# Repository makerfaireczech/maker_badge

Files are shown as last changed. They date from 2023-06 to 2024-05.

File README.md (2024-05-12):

# Maker badge
The Maker badge board is the official badge board for Maker Faire's in the Czech republic. The main purpose is to show visitors/exhibitors name and/or project, but the secondary goal is to have at each Maker Faire some interactive game so people can have more fun at the time of the visit.

This board supports [Arduino](https://github.com/espressif/arduino-esp32) and [CircuitPython](https://learn.adafruit.com/welcome-to-circuitpython) platform. 

CircuitPython will be **primary** platform for this board because it is very easy to use, and anybody who will buy a board at some Maker Fair should be able very easily change (at least) her/his name on the display, so anybody knows the name of the person when they start chatting about something.  

I will try to add as many examples for both platforms, as I could, but I already saw few very interesting projects.

## How to use this board in 5 steps:  

1) Connect USB-C cable to the board and turn it on. 
Either use a slide switch (top = OFF, down = ON) or move the jumper to the middle pins. This depends on the version which you have. 

2) Locate drive name "**Circuitpy**" and open **code.py** in some text editor. 
We recommend using **Mu editor**, but even Notepad will work. 

3) Find a line where is **"Jmeno"** (Name), **"Prijmeni"** (Surname), **"Firma/Projekt"** (Company/Project) and change it to whatever suit your need. 
There is yet no "auto aligning", so you have to also change X & Y coordinates for particular text. 

4) Save it via **CTRL+S/CMD+S** or you application menu for that. If the screen does not refresh, push the RESET button. 

5) Unplug the USB cable, put the strap around your neck, and wear it with pride. 

## Board version

There are currently following revisions of the board:

- rev. A : this version was distributed by me and it was using **212 x 104 px** e-ink display with UC8151D driver
- rev. B : this board was assembled by me for Maker Faire Prague 2022 and it was using **250 x 122 px** e-ink display with SSD1680 driver from Make More. It contains the same type of components as rev. A .  
- rev. C (with rev. B markings at the back): this board was assembled by PCBWay and it was using **250 x 122 px** e-ink display with SSD1680 driver from Make More. Some of the components are different because the original parts were not available due to chip shortage. These boards were distributed between Maker Faire Brno 2022 (22 - 23/10/2022) and Maker Faire Prague 2023 (10 - 11/6/2023).
- rev. D : this board was assembled by PCBWay and it contains these changes:
	- slide switch for power control instead of jumper over pins
	- transistor at e-ink display power line to save power 
	- transistor at resistor divider for battery measuring
	- CR2032 holder was removed to save the cost of the board

	These boards were distributed at Maker Faire Prague 2023 (10 - 11/6/2023) and onwards.

## Where can you buy it? 

[Makermarket](https://www.makermarket.cz/maker-badge)

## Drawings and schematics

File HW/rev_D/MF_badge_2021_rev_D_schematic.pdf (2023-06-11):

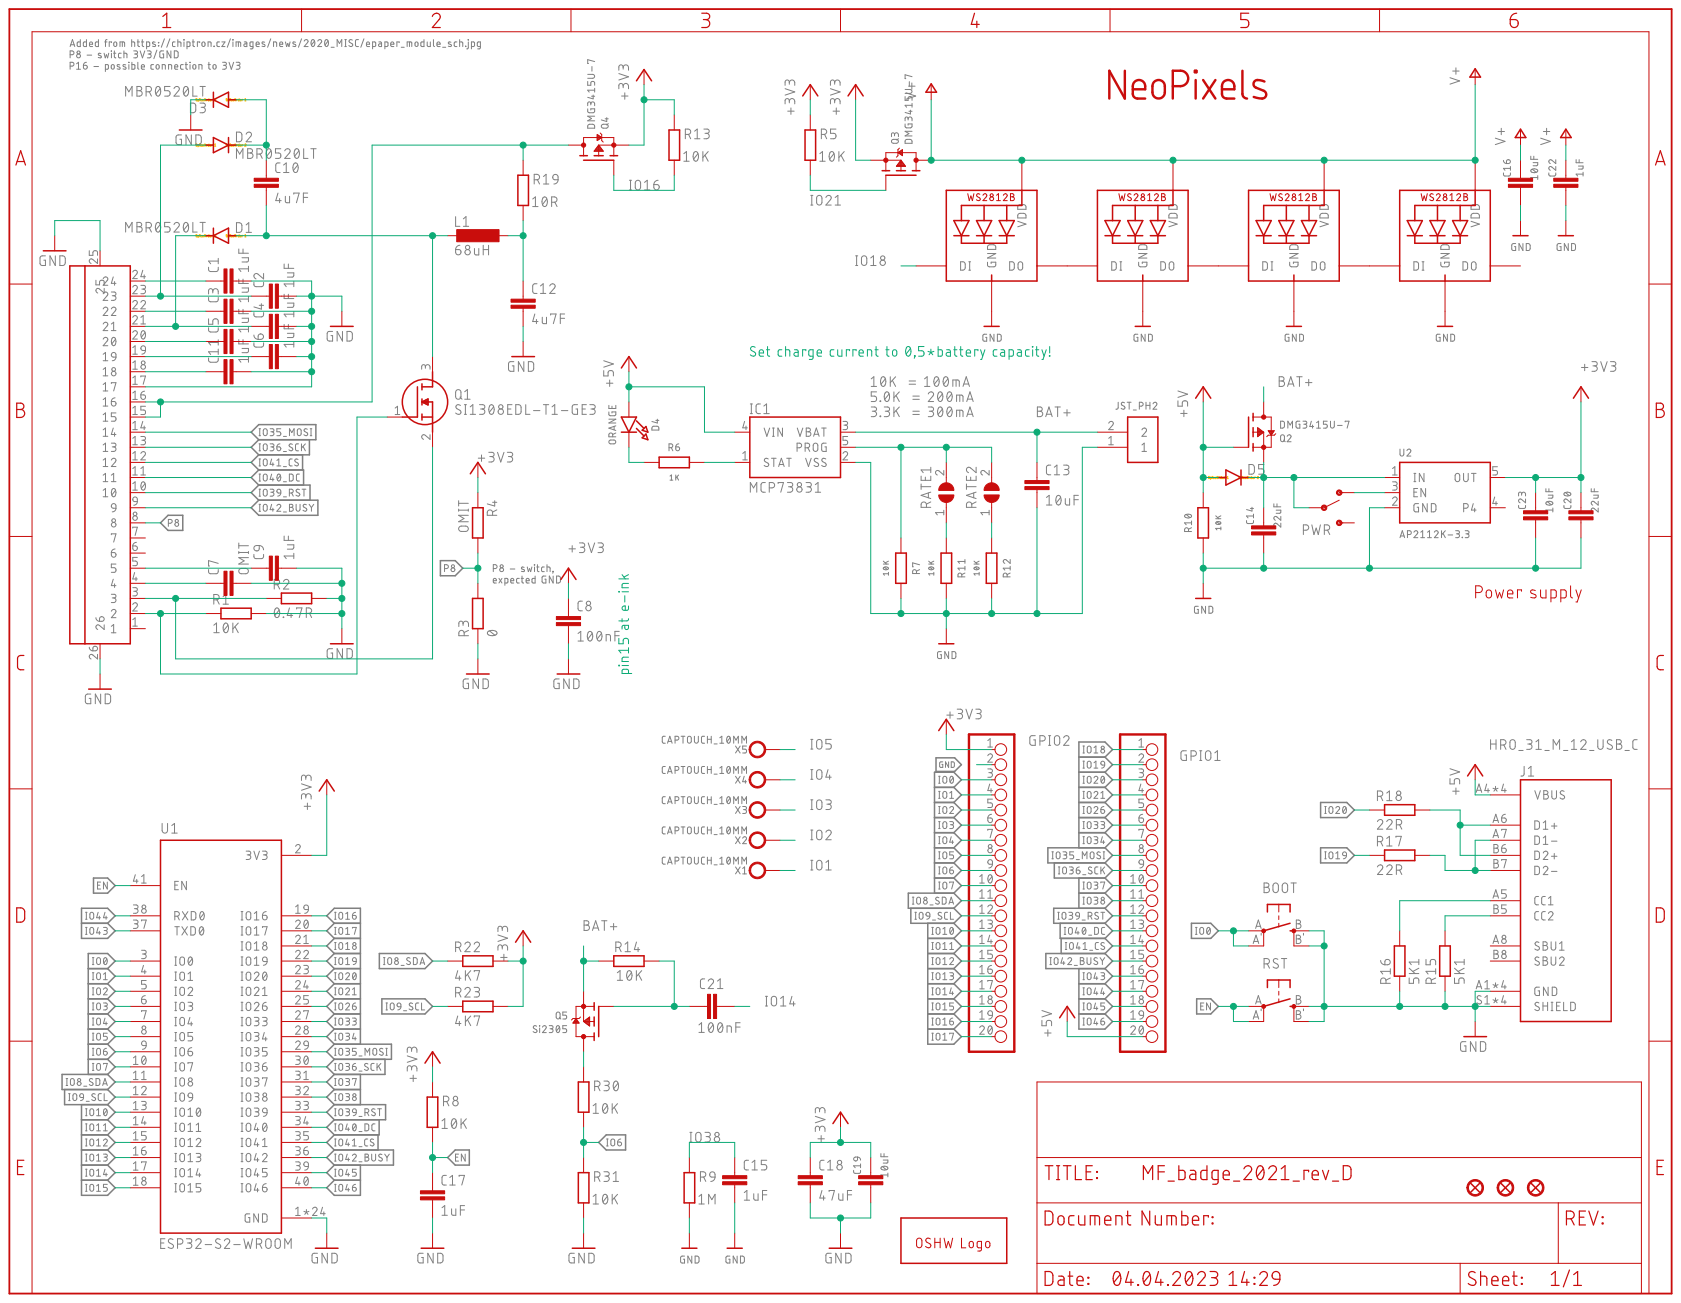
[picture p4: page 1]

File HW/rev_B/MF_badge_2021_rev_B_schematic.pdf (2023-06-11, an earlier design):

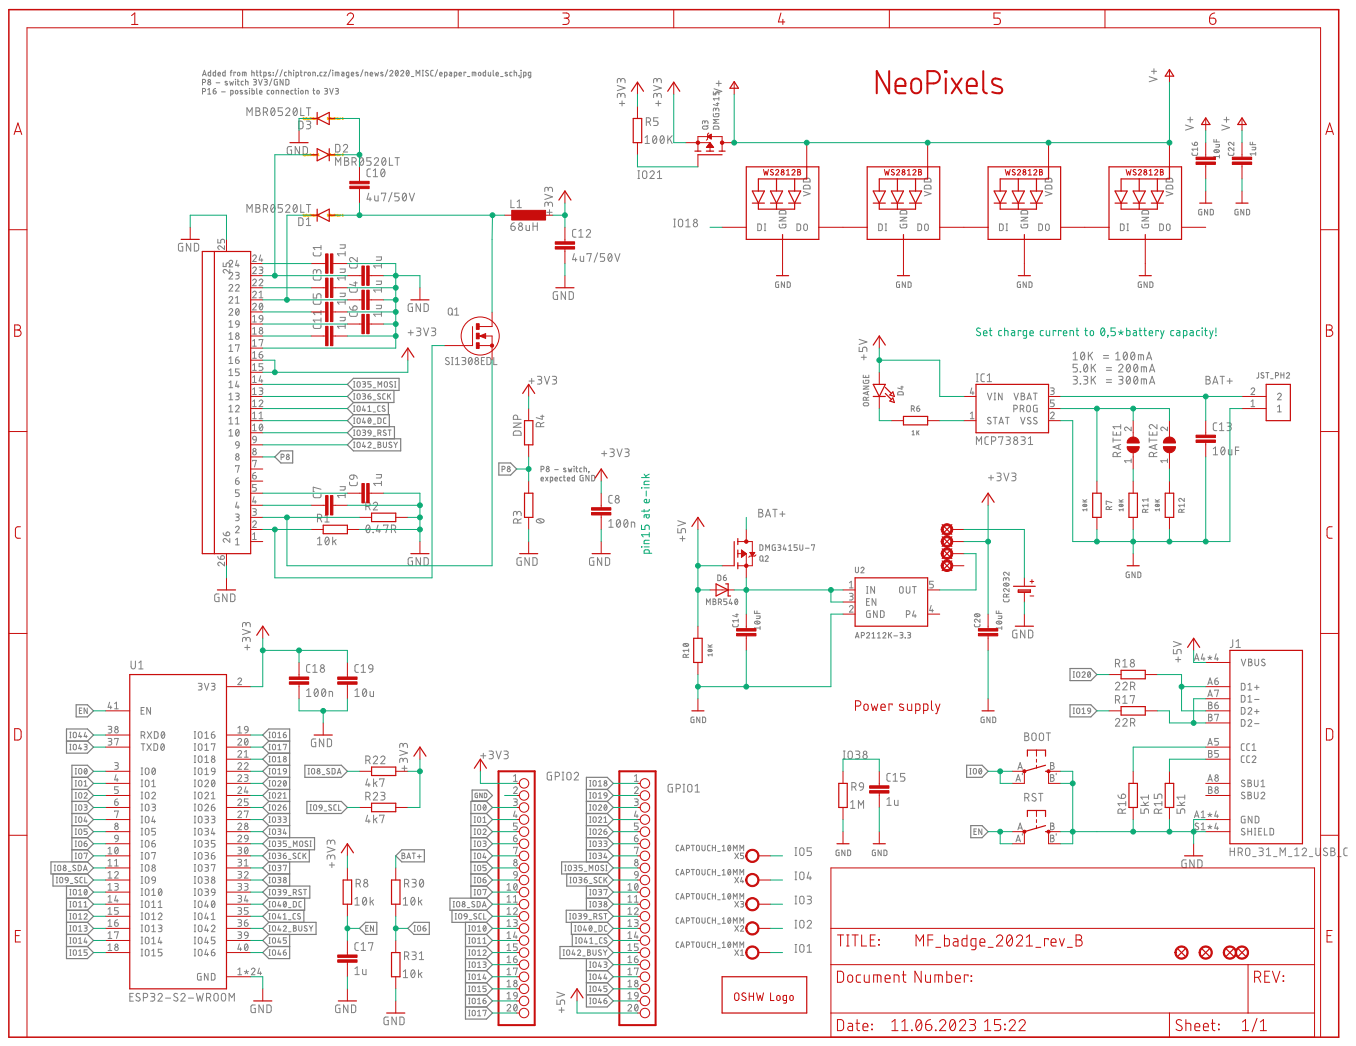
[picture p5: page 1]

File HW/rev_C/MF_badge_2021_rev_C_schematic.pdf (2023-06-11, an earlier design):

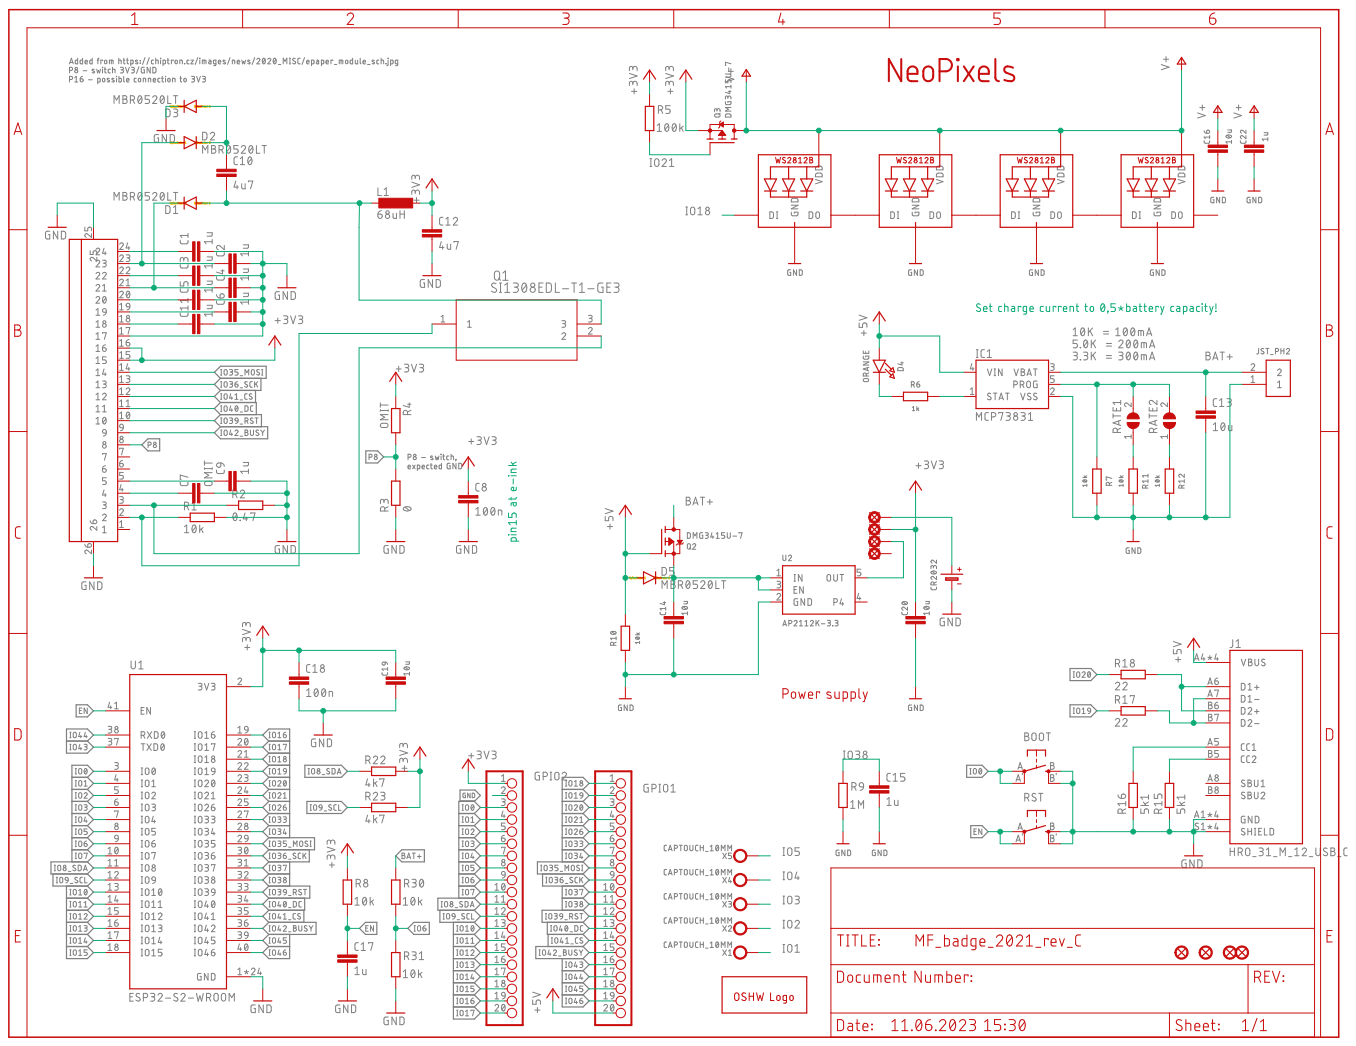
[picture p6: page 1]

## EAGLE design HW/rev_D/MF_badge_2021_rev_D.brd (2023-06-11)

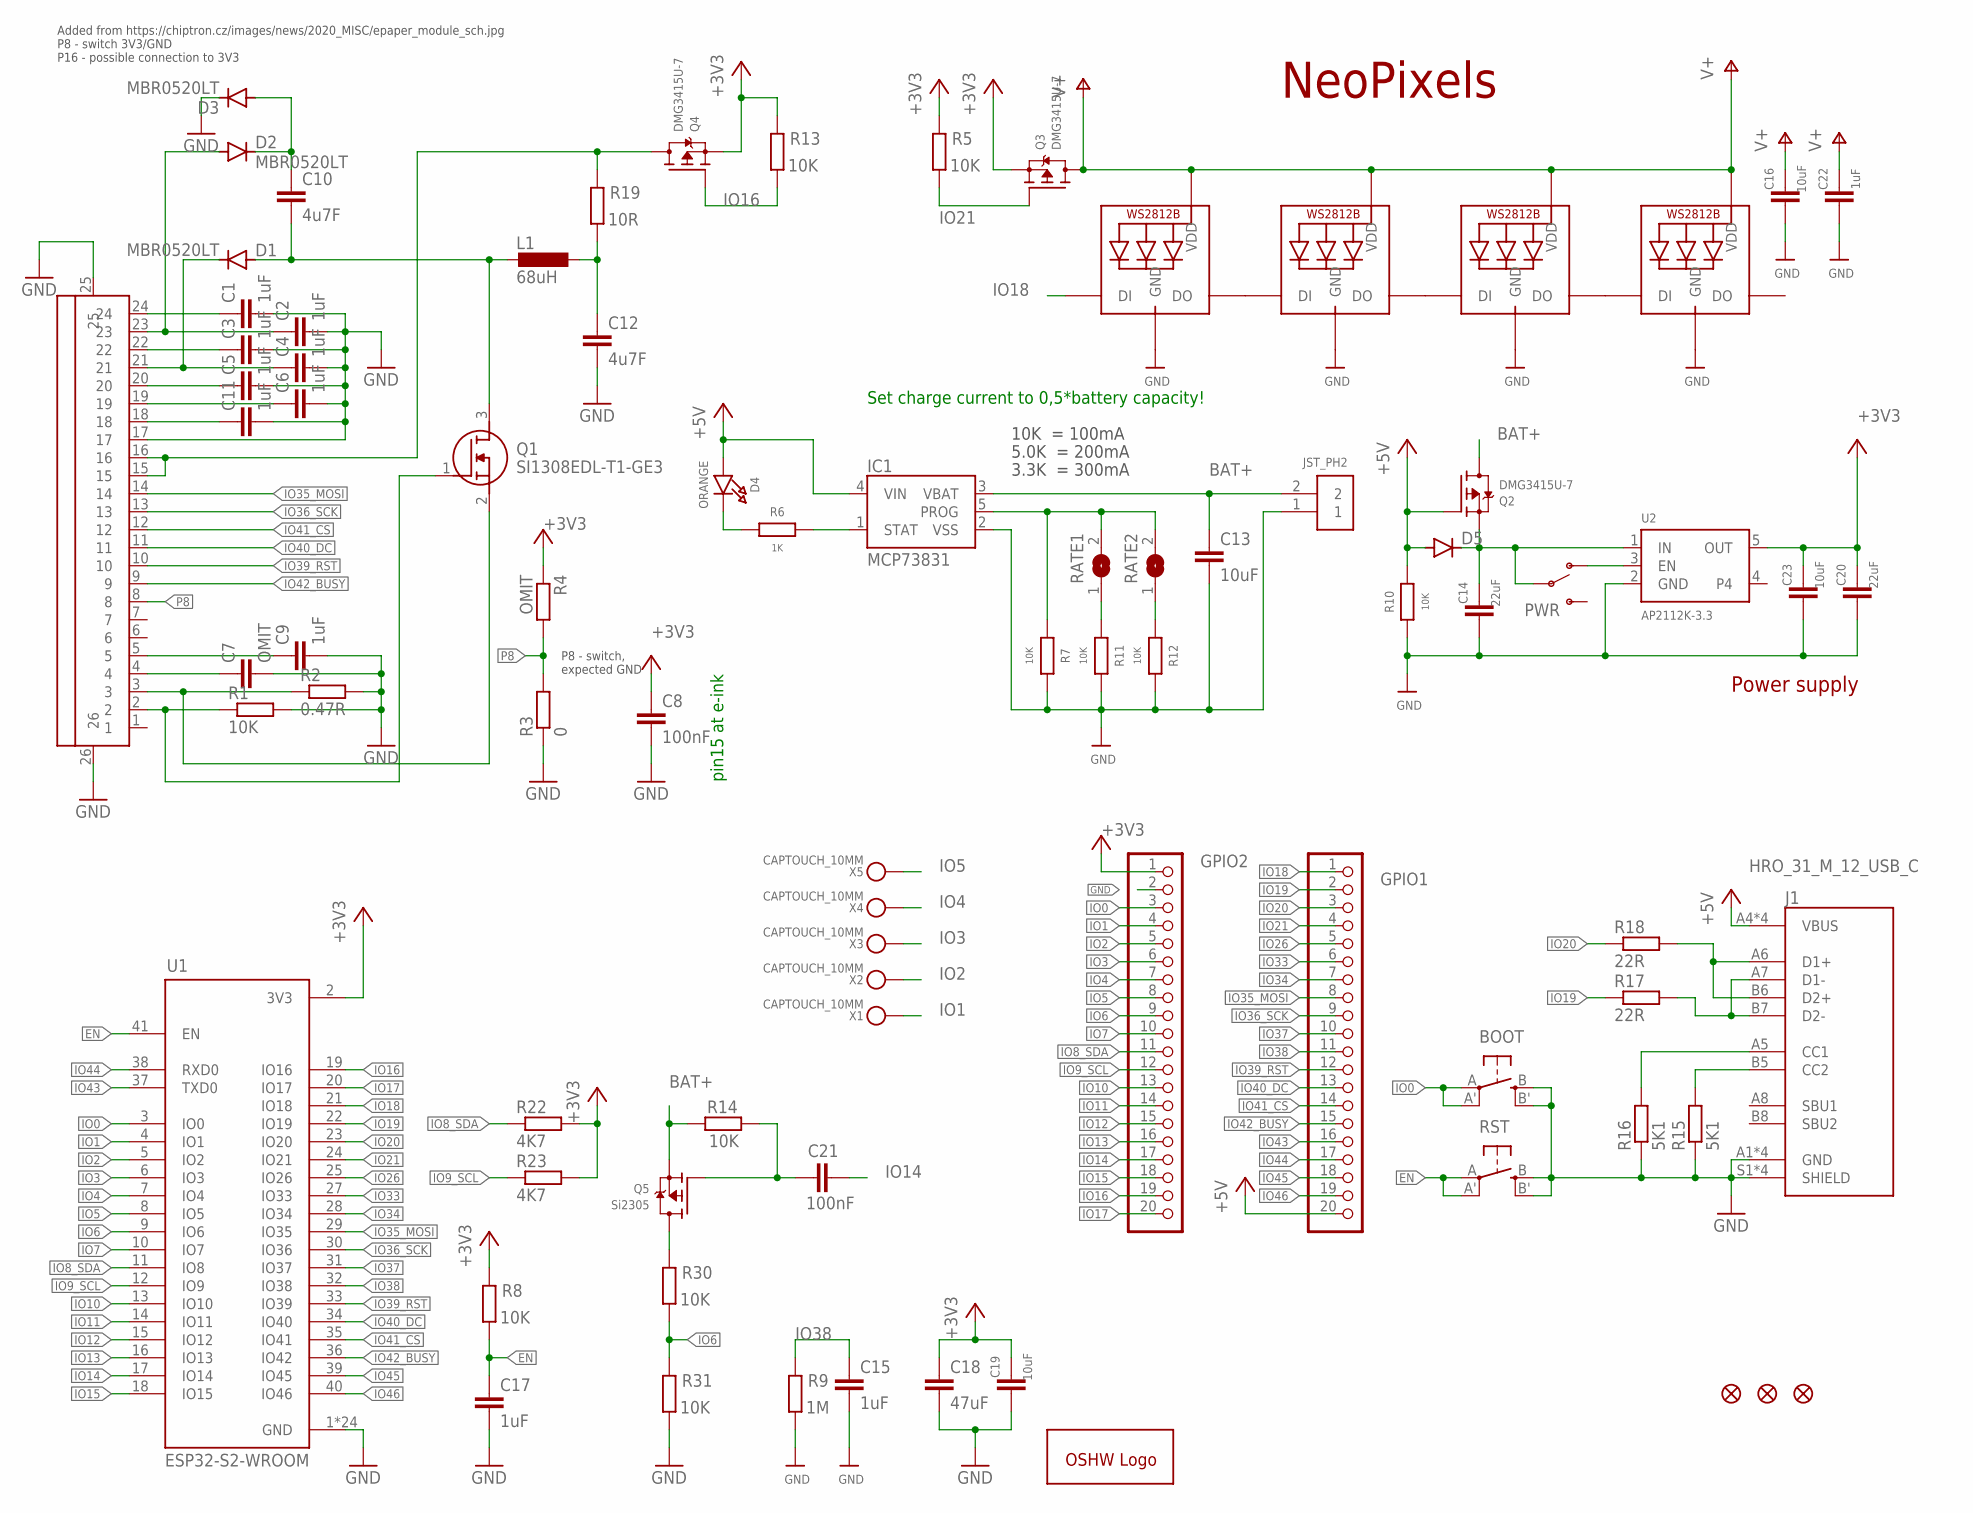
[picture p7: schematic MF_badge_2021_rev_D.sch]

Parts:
BOOT: BUTTON_KMR2_4.6X2.8
C1, C2, C3, C4, C5, C6, C9, C11, C15, C17, C22: 1uF; C0805
C7: OMIT; C0805
C8, C21: 100nF; C0805
C10, C12: 4u7F; C0805
C13, C16, C19, C23: 10uF; C0805
C14, C20: 22uF; C0805
C18: 47uF; C0805
D1, D2, D3, D5: MBR0520LT; SOD123
D4: ORANGE; CHIPLED_0805_NOOUTLINE
FID1, FID2, FID3: FIDUCIAL""; FIDUCIAL_1MM
GOLD_ORB_SM1: OSHWLOGO_; OSHW_5MM_LOGO
GPIO1, GPIO2: PINHD-1X20; 1X20
IC1: MCP73831; SOT95P290X120-5
J1: HRO_31_M_12_USB_C
L1: 68uH; L4532P
LED2, LED3, LED4, LED5: WS2812B5050; WS2812B
PWR: SWITCH-SPDT-SMD-RIGHT-ANGLE; SWITCH_SPST_SMD_A
Q1: SI1308EDL-T1-GE3; SOT65P210X110-3N
Q2, Q3, Q4: DMG3415U-7; SOT23-R
Q5: Si2305; SOT23-R
R1, R5, R7, R8, R10, R11, R12, R13, R14, R30, R31: 10K; R0805
R2: 0.47R; R0805
R3: 0; R0805
R4: OMIT; R0805
R6: 1K; R0805
R9: 1M; R0805
R15, R16: 5K1; R0805
R17, R18: 22R; R0805
R19: 10R; R0805
R22, R23: 4K7; R0805
RATE1, RATE2: SOLDERJUMPER; SOLDERJUMPER_ARROW_NOPASTE
RST: BUTTON_KMR2_4.6X2.8
U1: ESP32-S2-WROOM; XCVR_ESP32-S2-WROOM
U2: AP2112K-3.3; SOT23-5
U$1: 2.13_EINK
U$8: JST_PH2; JSTPH2
X1, X2, X3, X4, X5: CAPTOUCH_10MM; CAPTOUCH_6X9MM

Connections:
+3V3: C8.1, C18.1, C19.1, C20.1, C23.1, GPIO2.1, Q3.2 (S), Q4.2 (S), R4.1, R5.2, R8.2, R13.2, R22.2, R23.2, U1.2 (3V3), U2.5 (OUT)
+5V: D4.A, D5.A, GPIO1.20, IC1.4 (VIN), J1.A4 (VBUS), J1.A9 (VBUS), J1.B4 (VBUS), J1.B9 (VBUS), Q2.1 (G), R10.2
BAT+: C13.1, IC1.3 (VBAT), Q2.3 (D), Q5.2 (S), R14.2, U$8.2
D+_CON: J1.A6 (D1+), J1.B6 (D2+), R18.2
D-_CON: J1.A7 (D1-), J1.B7 (D2-), R17.2
EN: C17.1, R8.1, RST.A, RST.A' (P1), U1.41 (EN)
GND: BOOT.B (S), BOOT.B' (S1), C1.2, C2.2, C3.2, C4.2, C5.2, C6.2, C7.2, C8.2, C9.2, C11.2, C12.2, C13.2, C14.2, C15.2, C16.2, C17.2, C18.2, C19.2, C20.2, C22.2, C23.2, D3.C, GPIO2.2, IC1.2 (VSS), J1.A1 (GND), J1.A12 (GND), J1.B1 (GND), J1.B12 (GND), J1.S1 (SHIELD), J1.S2 (SHIELD), J1.S3 (SHIELD), J1.S4 (SHIELD), LED2.3-GND (GND), LED3.3-GND (GND), LED4.3-GND (GND), LED5.3-GND (GND), R1.2, R2.2, R3.1, R7.2, R9.1, R10.1, R11.2, R12.2, R15.1, R16.1, R31.1, RST.B (S), RST.B' (S1), U1.1 (GND), U1.26 (GND), U1.42 (GND), U1.43.1 (GND), U1.43.2 (GND), U1.43.3 (GND), U1.43.4 (GND), U1.43.5 (GND), U1.43.6 (GND), U1.43.7 (GND), U1.43.8 (GND), U1.43.9 (GND), U1.43.10 (GND), U1.43.11 (GND), U1.43.12 (GND), U1.43.13 (GND), U1.43.14 (GND), U1.43.15 (GND), U1.43.16 (GND), U1.43.17 (GND), U1.43.18 (GND), U1.43.19 (GND), U1.43.20 (GND), U1.43.21 (GND), U2.2 (GND), U$1.17, U$1.25, U$1.26, U$8.1
IO0: BOOT.A, BOOT.A' (P1), GPIO2.3, U1.3 (IO0)
IO1: GPIO2.4, U1.4 (IO1), X1.P$1
IO2: GPIO2.5, U1.5 (IO2), X2.P$1
IO3: GPIO2.6, U1.6 (IO3), X3.P$1
IO4: GPIO2.7, U1.7 (IO4), X4.P$1
IO5: GPIO2.8, U1.8 (IO5), X5.P$1
IO6: GPIO2.9, R30.1, R31.2, U1.9 (IO6)
IO7: GPIO2.10, U1.10 (IO7)
IO8_SDA: GPIO2.11, R22.1, U1.11 (IO8)
IO9_SCL: GPIO2.12, R23.1, U1.12 (IO9)
IO10: GPIO2.13, U1.13 (IO10)
IO11: GPIO2.14, U1.14 (IO11)
IO12: GPIO2.15, U1.15 (IO12)
IO13: GPIO2.16, U1.16 (IO13)
IO14: C21.2, GPIO2.17, U1.17 (IO14)
IO15: GPIO2.18, U1.18 (IO15)
IO16: GPIO2.19, Q4.1 (G), R13.1, U1.19 (IO16)
IO17: GPIO2.20, U1.20 (IO17)
IO18: GPIO1.1, LED2.4-DIN (DI), U1.21 (IO18)
IO19: GPIO1.2, R17.1, U1.22 (IO19)
IO20: GPIO1.3, R18.1, U1.23 (IO20)
IO21: GPIO1.4, Q3.1 (G), R5.1, U1.24 (IO21)
IO26: GPIO1.5, U1.25 (IO26)
IO33: GPIO1.6, U1.27 (IO33)
IO34: GPIO1.7, U1.28 (IO34)
IO35_MOSI: GPIO1.8, U1.29 (IO35), U$1.14
IO36_SCK: GPIO1.9, U1.30 (IO36), U$1.13
IO37: GPIO1.10, U1.31 (IO37)
IO38: C15.1, GPIO1.11, R9.2, U1.32 (IO38)
IO39_RST: GPIO1.12, U1.33 (IO39), U$1.10
IO40_DC: GPIO1.13, U1.34 (IO40), U$1.11
IO41_CS: GPIO1.14, U1.35 (IO41), U$1.12
IO42_BUSY: GPIO1.15, U1.36 (IO42), U$1.9
IO43: GPIO1.16, U1.37 (TXD0)
IO44: GPIO1.17, U1.38 (RXD0)
IO45: GPIO1.18, U1.39 (IO45)
IO46: GPIO1.19, U1.40 (IO46)
unnamed: C1.1, U$1.24
unnamed: C2.1, D2.A, U$1.23
unnamed: C3.1, U$1.22
unnamed: C4.1, D1.C, U$1.21
unnamed: C5.1, U$1.20
unnamed: C6.1, U$1.19
unnamed: C11.1, U$1.18
unnamed: IC1.1 (STAT), R6.2
unnamed: C14.1, D5.C, PWR.2, Q2.2 (S), U2.1 (IN)
unnamed: Q1.2 (S), R2.1, U$1.3
unnamed: C9.1, U$1.5
unnamed: C7.1, U$1.4
unnamed: Q1.1 (G), R1.1, U$1.2
unnamed: D4.C, R6.1
unnamed: C10.1, D2.C, D3.A
unnamed: LED2.2-DOUT (DO), LED3.4-DIN (DI)
unnamed: PWR.1 (O), U2.3 (EN)
unnamed: C10.2, D1.A, L1.2, Q1.3 (D)
unnamed: R11.1, RATE1.1
unnamed: R12.1, RATE2.1
unnamed: LED4.2-DOUT (DO), LED5.4-DIN (DI)
unnamed: J1.B5 (CC2), R15.2
unnamed: J1.A5 (CC1), R16.2
unnamed: LED3.2-DOUT (DO), LED4.4-DIN (DI)
unnamed: Q4.3 (D), R19.2, U$1.15, U$1.16
unnamed: C12.1, L1.1, R19.1
unnamed: Q5.3 (D), R30.2
unnamed: C21.1, Q5.1 (G), R14.1
P8: R3.2, R4.2, U$1.8
PROG: IC1.5 (PROG), R7.1, RATE1.2, RATE2.2
V+: C16.1, C22.1, LED2.1-VDD (VDD), LED3.1-VDD (VDD), LED4.1-VDD (VDD), LED5.1-VDD (VDD), Q3.3 (D)

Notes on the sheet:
P8 - switch, expected GND
Added from https://chiptron.cz/images/news/2020_MISC/epaper_module_sch.jpg P8 - switch 3V3/GND P16 - possible connection to 3V3
10K = 100mA
5.0K = 200mA
3.3K = 300mA
Set charge current to 0,5*battery capacity!
Power supply
pin15 at e-ink
NeoPixels

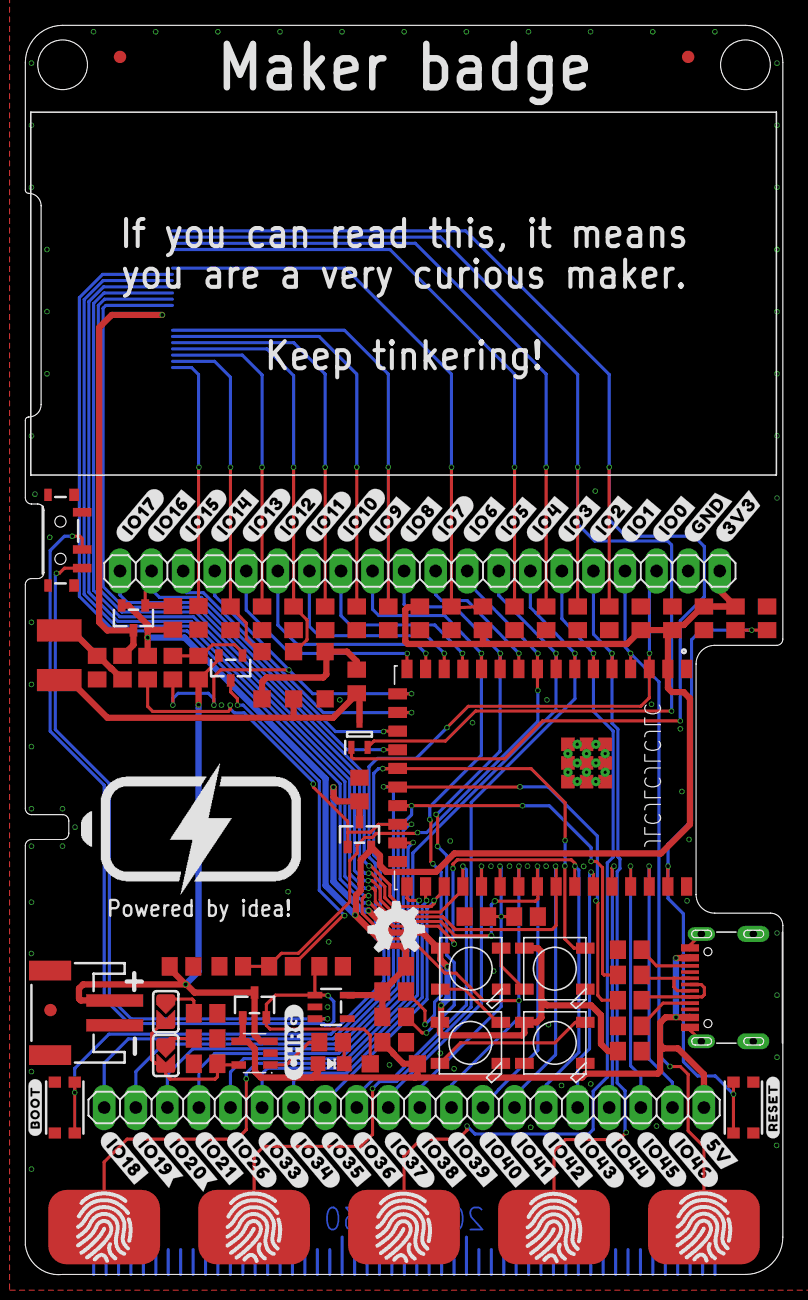
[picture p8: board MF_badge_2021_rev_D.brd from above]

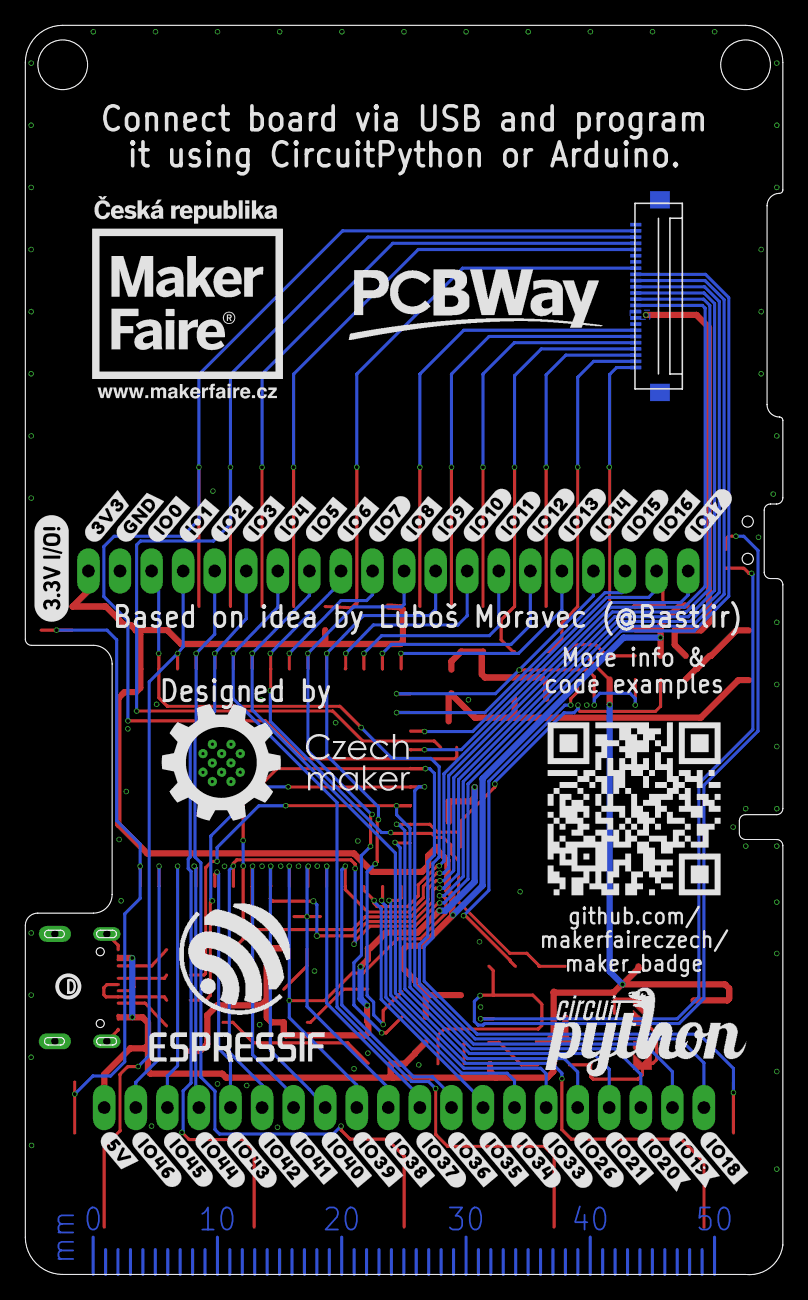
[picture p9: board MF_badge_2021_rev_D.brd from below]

Board: 2 copper layers, 61.0 x 100.5 mm, 167 parts (41 on the bottom side), 75 nets.

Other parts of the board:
U$2, U$92: #IO43#0
U$3, U$93: #IO44#0
U$4, U$33: #IO17#0
U$6, U$34: #IO16#0
U$7: #BOOT#0
U$9: #RESET#0
U$10: PCBFEAT-REV-040
U$12: #CHRG#0
U$16, U$77: #IO18#0
U$17, U$78: #IO19#0
U$18, U$79: #IO20#0
U$19, U$80: #IO21#0
U$20, U$81: #IO26#0
U$21, U$82: #IO33#0
U$22, U$83: #IO34#0
U$23, U$84: #IO35#0
U$24, U$85: #IO36#0
U$25, U$87: #IO38#0
U$26, U$86: #IO37#0
U$27, U$88: #IO39#0
U$28, U$89: #IO40#0
U$29, U$90: #IO41#0
U$30, U$91: #IO42#0
U$31, U$94: #IO45#0
U$32, U$95: #IO46#0
U$35, U$57: #IO15#0
U$37, U$58: #IO14#0
U$38, U$59: #IO13#0
U$39, U$60: #IO12#0
U$40, U$65: #IO11#0
U$41, U$66: #IO10#0
U$42, U$67: #IO9#0
U$43, U$68: #IO8#0
U$44, U$69: #IO7#0
U$45, U$70: #IO6#0
U$46, U$71: #IO5#0
U$47, U$72: #IO4#0
U$48, U$73: #IO3#0
U$49, U$74: #IO2#0
U$50, U$75: #IO1#0
U$51, U$76: #IO0#0
U$96, U$100: #GND#0
U$97, U$101: #3V3#0
U$98, U$99: #5V#0

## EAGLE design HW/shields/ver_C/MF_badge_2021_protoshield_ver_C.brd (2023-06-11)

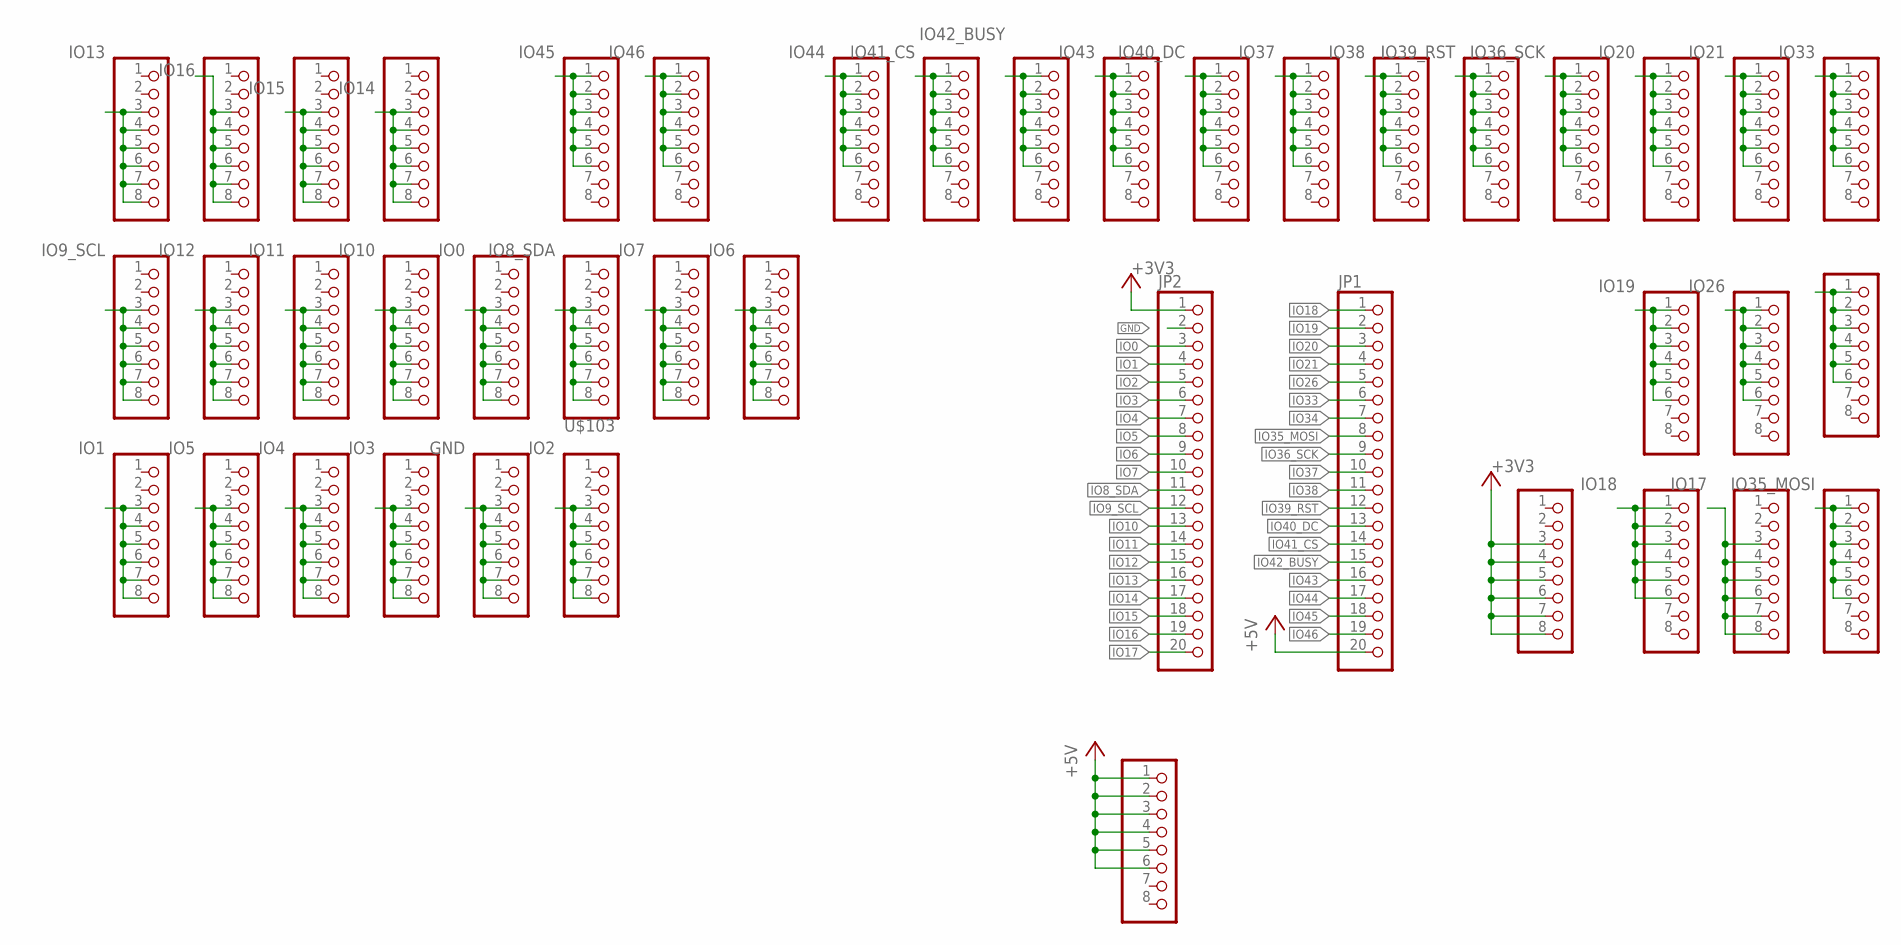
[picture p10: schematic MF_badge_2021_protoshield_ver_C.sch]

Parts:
JP1, JP2: PINHD-1X20_CLEANBIG; 1X20-CLEANBIG
U$1, U$5, U$7, U$8, U$9, U$10, U$11, U$12, U$13, U$14, U$15, U$36, U$52, U$53, U$54, U$55, U$56, U$61, U$62, U$63, U$64, U$102, U$103, U$104, U$105, U$106, U$107, U$108, U$109, U$110, U$111, U$112, U$113, U$114, U$115, U$116, U$117, U$118, U$119, U$120: PINHD-1X8CLEANBIG; 1X08-CLEANBIG

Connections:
+3V3: JP2.1, U$1.3, U$1.4, U$1.5, U$1.6, U$1.7, U$1.8
+5V: JP1.20, U$102.1, U$102.2, U$102.3, U$102.4, U$102.5, U$102.6
GND: JP2.2, U$120.3, U$120.4, U$120.5, U$120.6, U$120.7, U$120.8
IO0: JP2.3, U$115.3, U$115.4, U$115.5, U$115.6, U$115.7, U$115.8
IO1: JP2.4, U$119.3, U$119.4, U$119.5, U$119.6, U$119.7, U$119.8
IO2: JP2.5, U$103.3, U$103.4, U$103.5, U$103.6, U$103.7, U$103.8
IO3: JP2.6, U$118.3, U$118.4, U$118.5, U$118.6, U$118.7, U$118.8
IO4: JP2.7, U$117.3, U$117.4, U$117.5, U$117.6, U$117.7, U$117.8
IO5: JP2.8, U$116.3, U$116.4, U$116.5, U$116.6, U$116.7, U$116.8
IO6: JP2.9, U$114.3, U$114.4, U$114.5, U$114.6, U$114.7, U$114.8
IO7: JP2.10, U$113.3, U$113.4, U$113.5, U$113.6, U$113.7, U$113.8
IO8_SDA: JP2.11, U$112.3, U$112.4, U$112.5, U$112.6, U$112.7, U$112.8
IO9_SCL: JP2.12, U$111.3, U$111.4, U$111.5, U$111.6, U$111.7, U$111.8
IO10: JP2.13, U$110.3, U$110.4, U$110.5, U$110.6, U$110.7, U$110.8
IO11: JP2.14, U$109.3, U$109.4, U$109.5, U$109.6, U$109.7, U$109.8
IO12: JP2.15, U$108.3, U$108.4, U$108.5, U$108.6, U$108.7, U$108.8
IO13: JP2.16, U$107.3, U$107.4, U$107.5, U$107.6, U$107.7, U$107.8
IO14: JP2.17, U$106.3, U$106.4, U$106.5, U$106.6, U$106.7, U$106.8
IO15: JP2.18, U$105.3, U$105.4, U$105.5, U$105.6, U$105.7, U$105.8
IO16: JP2.19, U$104.3, U$104.4, U$104.5, U$104.6, U$104.7, U$104.8
IO17: JP2.20, U$7.3, U$7.4, U$7.5, U$7.6, U$7.7, U$7.8
IO18: JP1.1, U$5.1, U$5.2, U$5.3, U$5.4, U$5.5, U$5.6
IO19: JP1.2, U$8.1, U$8.2, U$8.3, U$8.4, U$8.5, U$8.6
IO20: JP1.3, U$9.1, U$9.2, U$9.3, U$9.4, U$9.5, U$9.6
IO21: JP1.4, U$10.1, U$10.2, U$10.3, U$10.4, U$10.5, U$10.6
IO26: JP1.5, U$11.1, U$11.2, U$11.3, U$11.4, U$11.5, U$11.6
IO33: JP1.6, U$12.1, U$12.2, U$12.3, U$12.4, U$12.5, U$12.6
IO34: JP1.7, U$13.1, U$13.2, U$13.3, U$13.4, U$13.5, U$13.6
IO35_MOSI: JP1.8, U$14.1, U$14.2, U$14.3, U$14.4, U$14.5, U$14.6
IO36_SCK: JP1.9, U$15.1, U$15.2, U$15.3, U$15.4, U$15.5, U$15.6
IO37: JP1.10, U$36.1, U$36.2, U$36.3, U$36.4, U$36.5, U$36.6
IO38: JP1.11, U$52.1, U$52.2, U$52.3, U$52.4, U$52.5, U$52.6
IO39_RST: JP1.12, U$53.1, U$53.2, U$53.3, U$53.4, U$53.5, U$53.6
IO40_DC: JP1.13, U$54.1, U$54.2, U$54.3, U$54.4, U$54.5, U$54.6
IO41_CS: JP1.14, U$55.1, U$55.2, U$55.3, U$55.4, U$55.5, U$55.6
IO42_BUSY: JP1.15, U$56.1, U$56.2, U$56.3, U$56.4, U$56.5, U$56.6
IO43: JP1.16, U$61.1, U$61.2, U$61.3, U$61.4, U$61.5, U$61.6
IO44: JP1.17, U$62.1, U$62.2, U$62.3, U$62.4, U$62.5, U$62.6
IO45: JP1.18, U$63.1, U$63.2, U$63.3, U$63.4, U$63.5, U$63.6
IO46: JP1.19, U$64.1, U$64.2, U$64.3, U$64.4, U$64.5, U$64.6

Board: 2 copper layers, 42 parts (0 on the bottom side), 40 nets, no tracks yet.

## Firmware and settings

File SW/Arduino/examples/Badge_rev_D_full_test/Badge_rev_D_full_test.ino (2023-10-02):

#define ENABLE_GxEPD2_GFX 0 // we won't need the GFX base class
#include <GxEPD2_BW.h>
// Online tool for converting images to byte arrays:
// https://javl.github.io/image2cpp/

#include "Bitmap.h"
#include <WS2812FX.h> // from library manager 
#include "ESP32_RMT_Driver.h"

// ESP32-S2 e-ink pinout
#define BUSY 42
#define RST  39
#define DC   40
#define CS   41
#define PWR  16

bool testing = 0;
const int bootPin = 0;
int bootPinState;
int lastBootPinState = HIGH;
unsigned long nowTime;
bool allPressed, screenDrawn = 0;

// This is borrowed from Debounce example:
// the following variables are unsigned longs because the time, measured in
// milliseconds, will quickly become a bigger number than can be stored in an int.
unsigned long lastDebounceTime = 0;  // the last time the output pin was toggled
unsigned long debounceDelay = 50;    // the debounce time; increase if the output flickers

// This is borrowed from NeoPixel Ring simple sketch (c) 2013 Shae Erisson
// Which pin on the Arduino is connected to the NeoPixels?
#define ledPin    18
#define ledPower  21
// How many NeoPixels are attached to the board?
#define NUMPIXELS 4

// When setting up the NeoPixel library, we tell it how many pixels,
// and which pin to use to send signals. Note that for older NeoPixel
// strips you might need to change the third parameter -- see the
// strandtest example for more information on possible values.
WS2812FX neopixels(NUMPIXELS, ledPin, NEO_GRB + NEO_KHZ800);

// Instantiate the GxEPD2_BW class for our display type
GxEPD2_BW<GxEPD2_213_B74, GxEPD2_213_B74::HEIGHT> display(GxEPD2_213_B74(CS, DC, RST, BUSY)); // GDEM0213B74 128x250, SSD1680


void setup() {
  Serial.begin(115200);
  pinMode(bootPin, INPUT_PULLUP);
  pinMode(ledPower, OUTPUT);
  pinMode(PWR, OUTPUT);

  neopixels.init(); // initialize the ws2812fx instances

  neopixels.setBrightness(10); // set the overall LED brightnesses

  rmt_tx_int(RMT_CHANNEL_0, neopixels.getPin()); // assign ws2812fx1 to RMT channel 0

  neopixels.setCustomShow(myCustomShow1); // set the custom show function to forgo the NeoPixel
  digitalWrite(ledPower, LOW); //turn on power for LED´s
  digitalWrite(PWR, LOW); //turn on power for screen
  neopixels.strip_off(); //clear all LED´s 

  // wait for display to become available
  display.init(115200);
  // display Czech maker logo on the display
  drawBitmaps(czm_logo);
  //wait 2 secomds between screens
  delay(2000);
  //display second screen
  drawBitmaps(start_screen);
}

void loop() {
  neopixels.service(); // service each ws2812fx instance
  if (!testing) {
    readBootPin();
  }
  if (testing) {
    readTouchPins();
  }
  if (allPressed && !testing && !screenDrawn) {
    if ((millis() - nowTime) > 1000) {
      finalScreen();
    }
  }
}

//This is function from GxEPD library example
void drawBitmaps(const unsigned char *bitmap) {
  // Configure the display according to our preferences
  display.setRotation(2);
  display.setFullWindow();
  // Display the bitmap image
  display.firstPage();
  do {
    display.fillScreen(GxEPD_WHITE);
    display.drawBitmap(0, 0, bitmap, display.epd2.WIDTH, display.epd2.HEIGHT, GxEPD_BLACK);
  } while (display.nextPage());
}

// This is borrowed from Debounce example :)
void readBootPin() {
  // read the state of the switch into a local variable:
  int reading = digitalRead(bootPin);

  // check to see if you just pressed the button
  // (i.e. the input went from LOW to HIGH), and you've waited long enough
  // since the last press to ignore any noise:

  // If the switch changed, due to noise or pressing:
  if (reading != lastBootPinState) {
    // reset the debouncing timer
    lastDebounceTime = millis();
  }

  if ((millis() - lastDebounceTime) > debounceDelay) {
    // whatever the reading is at, it's been there for longer than the debounce
    // delay, so take it as the actual current state:

    // if the button state has changed:
    if (reading != bootPinState) {
      bootPinState = reading;

      // only toggle the LED if the new button state is HIGH
      if (bootPinState == LOW) {
        Serial.println("Button state is: " + String(bootPinState));
        drawBitmaps(second_screen);
        testing = 1;
      }
    }
  }

  // save the reading. Next time through the loop, it'll be the lastButtonState:
  lastBootPinState = reading;
}

void readTouchPins() {
  uint16_t touchread;
  byte atLeastOneTouch = 0;
  for (int i = 0; i < 5; i++) {
    // (5 - i) because pins order is reversed
    touchread = touchRead(5 - i);
    if (touchread > 25000 ) {
      Serial.printf("Captouch #%0d reading: %d\n", i, touchread);
      if (i != 4) {
        showRGB(i, RED);
      }
      else {
        showRGB(i, GREEN);
        allPressed = 1;
        testing = 0;
      }
      atLeastOneTouch++;
    }
    delay(40);
  }
  // If no touch detected in last cycle, turn off all LEDs
  if (atLeastOneTouch == 0) {
    neopixels.show();
  }
}

void showRGB(int led, unsigned int color) {
  // parameters: index, start, stop, mode, color, speed, reverse
  if (led != 4 ) {
    neopixels.setSegment(0, led, led, FX_MODE_STATIC, color, 1000);
    neopixels.start(); // start'em up
  } else {
    neopixels.setSegment(0, 0, led, FX_MODE_STATIC, color, 1000);
    neopixels.start(); // start'em up
    nowTime = millis();
  }
}

void finalScreen() {
  neopixels.strip_off();
  drawBitmaps(third_screen);
  delay(2000);
  drawBitmaps(czm_logo);
  digitalWrite(ledPower, HIGH);
  screenDrawn = 1;
}

// Custom show functions which will use the RMT hardware to drive the LEDs.
// Need a separate function for each ws2812fx instance.
void myCustomShow1(void) {
  uint8_t *pixels = neopixels.getPixels();
  // numBytes is one more then the size of the ws2812fx's *pixels array.
  // the extra byte is used by the driver to insert the LED reset pulse at the end.
  uint16_t numBytes = neopixels.getNumBytes() + 1;
  rmt_write_sample(RMT_CHANNEL_0, pixels, numBytes, false); // channel 0
}

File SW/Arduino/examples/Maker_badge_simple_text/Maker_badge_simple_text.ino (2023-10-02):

// This example is based on GxEPD2_HelloWorld.ino by Jean-Marc Zingg

#define ENABLE_GxEPD2_GFX 0
#include <GxEPD2_BW.h> // including both doesn't hurt
#include <GxEPD2_3C.h> // including both doesn't hurt
#include <Fonts/FreeMonoBold12pt7b.h>

// Please define you maker badge version. Select A if you get badge earlier than 8/2022 a B if you get it after 8/2022

#define B

// ESP32-S2
#define BUSY 42
#define RST  39
#define DC   40
#define CS   41
#define PWR  16

#ifdef B
GxEPD2_BW<GxEPD2_213_B74, GxEPD2_213_B74::HEIGHT> display(GxEPD2_213_B74(CS, DC, RST, BUSY)); // GDEM0213B74 128x250, SSD1680
#else
GxEPD2_BW<GxEPD2_213_T5D, GxEPD2_213_T5D::HEIGHT> display(GxEPD2_213_T5D(CS, DC, RST, BUSY)); // GDEW0213T5D
#endif

void setup()
{
  pinMode(PWR, OUTPUT);
   digitalWrite(PWR, LOW); //turn on power for screen
  display.init(115200);
  simpleText();
  display.hibernate();

  esp_sleep_pd_config(ESP_PD_DOMAIN_RTC_PERIPH, ESP_PD_OPTION_OFF);
  esp_deep_sleep_start();
//esp_light_sleep_start();
}

const char firstLine[] = "Hello maker";
const char secondLine[] = "I am your";
const char thirdLine[] = "badge.";

void simpleText()
{
  display.setRotation(3);
  display.setFont(&FreeMonoBold12pt7b);
  display.setTextColor(GxEPD_BLACK);
  int16_t tbx, tby; uint16_t tbw, tbh;

  // center bounding box by transposition of origin:
  display.getTextBounds(firstLine, 0, 0, &tbx, &tby, &tbw, &tbh);
  uint16_t x1 = ((display.width() - tbw) / 2) - tbx;
  display.getTextBounds(secondLine, 0, 0, &tbx, &tby, &tbw, &tbh);
  uint16_t x2 = ((display.width() - tbw) / 2) - tbx;
  display.getTextBounds(thirdLine, 0, 0, &tbx, &tby, &tbw, &tbh);
  uint16_t x3 = ((display.width() - tbw) / 2) - tbx;
  uint16_t y = ((display.height() - tbh) / 2) - tby;
  display.setFullWindow();
  display.firstPage();
  do
  {
    display.fillScreen(GxEPD_WHITE);
    display.setCursor(x1, y-20);
    display.print(firstLine);
    display.setCursor(x2, y);
    display.print(secondLine);
    display.setCursor(x3, y + 20);
    display.print(thirdLine);
  }
  while (display.nextPage());
}

void loop() {
  };

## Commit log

2023-03-02 Update
    - removed CR2032 battery holder
    - changed battery measuring circuit to save power
    - add N-MOSFET to control 3V3 to e-ink displey
    - changed QR to match new project address
    [MF_badge_2021_rev_D.brd, MF_badge_2021_rev_D.sch]
2023-03-02 Update
    - schematic cleanup
    - power supply layout optimization
    - changed some R and C values
    - add hole for battery holder
    [MF_badge_2021_rev_D.brd, MF_badge_2021_rev_D.sch]
2023-03-06 Update
    - bigger slot for battery holder
    - GND stitching for better RF
    [MF_badge_2021_rev_D.brd]
2023-03-09 Update
    - add pin to drive Q4
    - changed pin labels to match reality
    - add .gitignore file
    [MF_badge_2021_rev_D.brd]
2023-03-09 Update MF_badge_2021_rev_D.sch
    - forget to add it in previous commit
    [MF_badge_2021_rev_D.sch]
2023-03-20 Verified design files for rev.D
    [MF_badge_2021_rev_D.brd, MF_badge_2021_rev_D.sch]
2023-03-24 Add ESPRESSIF logo
    [MF_badge_2021_rev_D.brd]
2023-04-02 Error fix for 3V3 line at e-ink display
    [MF_badge_2021_rev_D.brd, MF_badge_2021_rev_D.sch]
2023-04-02 Moved 3V3 for e-ink power pins before R19
    [MF_badge_2021_rev_D.brd, MF_badge_2021_rev_D.sch]
2023-06-11 Update
    - added schematics for all versions
    - added protoshield files
    - added files for rev. D
    - README update
    - removed unnecessary files
    [MF_badge_2021_protoshield_ver_A.brd, MF_badge_2021_protoshield_ver_A.sch, MF_badge_2021_protoshield_ver_B.brd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]
2023-07-10 Update
    - add simple Arduino example for rev. D
    - add bitmap + battery reading example for CircuitPython
2023-10-02 Update
    - comment update in Badge_rev_D_full_test.ino
    - typo fix in name of the skecth for simple text example
    - update Maker_badge_simple_text.ino example to work with rev.D version of the board
    [Badge_rev_D_full_test.ino, Maker_badge_simple_text.ino]

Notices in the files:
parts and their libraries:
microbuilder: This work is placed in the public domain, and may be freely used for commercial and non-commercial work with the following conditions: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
